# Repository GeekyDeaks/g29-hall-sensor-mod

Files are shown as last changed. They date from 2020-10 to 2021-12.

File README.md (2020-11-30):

# G29 Hall Sensor Mod

Modification to replace the stock potentiometers in the G29/G27 pedals with hall sensors

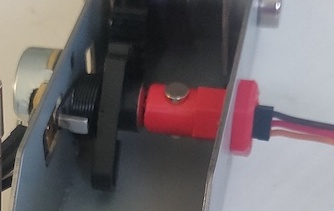
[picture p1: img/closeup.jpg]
closeup


There are two alternative designs in this repo

1. modification using the original pot as part of the magnet holder assembly (as show in the above image)
2. complete replacement of the original pot with a 3D printed design

Both designs require some additional parts to accompany the 3D model

1. 2x 6mm diameter 3mm high magnets
2. [A1324](https://docs.rs-online.com/958c/0900766b813d193a.pdf) hall effect sensor 

# Hall Sensor

Over the 70 degrees rotation the pedal rotates the pot axis, the output of the A1324 is very linear.  The chart below shows the output of the sensor compares to the output of the pot whilst both are connected in the same pedal:

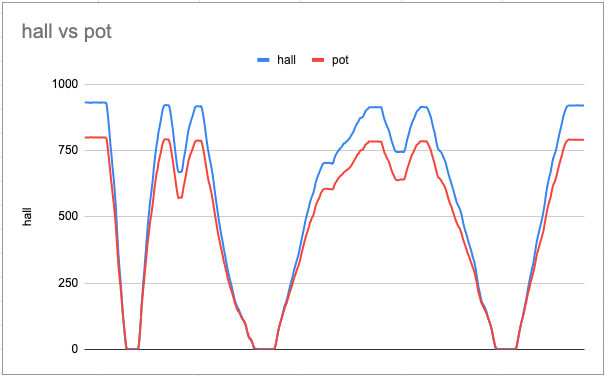
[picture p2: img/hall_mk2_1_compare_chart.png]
compare


The next chart shows an XY scatter of the pot vs the hall sensor readings for each sample taken:

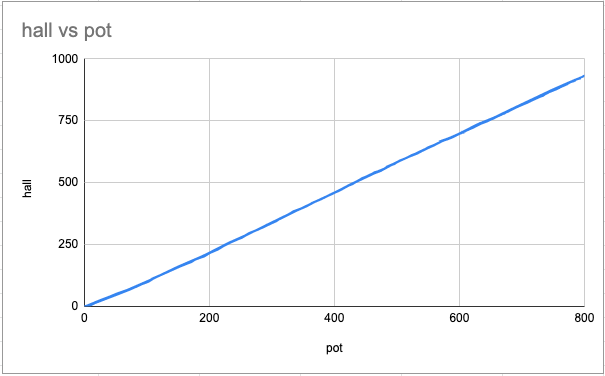
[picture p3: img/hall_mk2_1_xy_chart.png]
xy


The units of each plot are the 10 bit reading of the ADC in a Pro Micro Arduino

The A1324 is rated at 5V, but it was found during testing that it actually works at 3.3V, so it appears to be completely compatible with the G29.  There is however another variant, the [A1319](https://docs.rs-online.com/1a99/0900766b815eefb8.pdf), which is rated at 3.3V

# Mod design

This design engages with the stock potentiometer, using it as the base of the magnet holder.

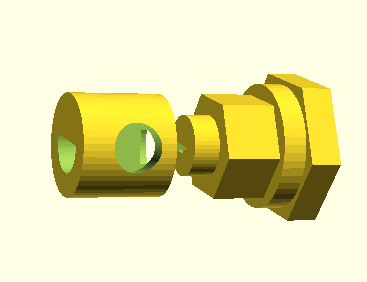
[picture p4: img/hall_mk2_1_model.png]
mod


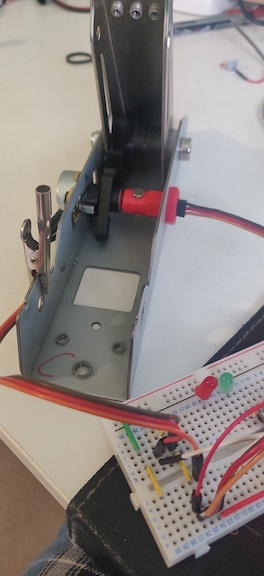
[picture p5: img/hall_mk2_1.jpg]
test


There are two alternatives to this design:

1. where the sensor leads exit the side of the assembly (mod/stl/side-exit-explode.stl)
2. where the sensor leads exit inside the assembly and therefore inside the pedal base (mod/stl/inner-exit-explode.stl)

# Replacement design

This completely replaces the stock potentiometer with a 3D printed replacement.  The tolerances are pretty tight, but can be relaxed a little with some additional silicone grease or suitable alternative.

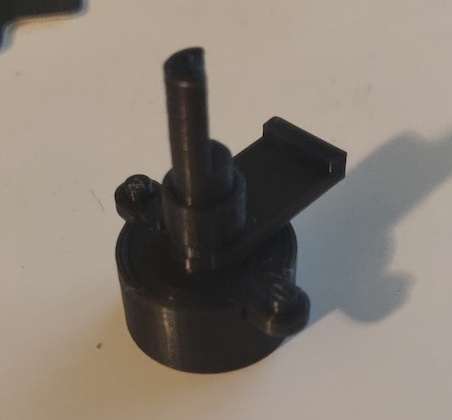
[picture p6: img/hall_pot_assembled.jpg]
assembled

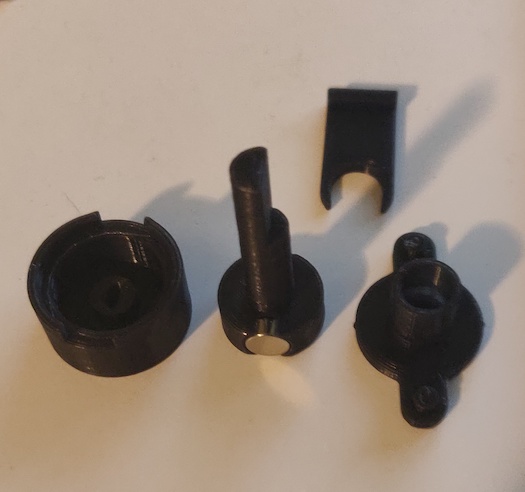
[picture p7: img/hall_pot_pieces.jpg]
explode


## STL

* [explode](pot/stl/explode.stl)
* [clip](pot/stl/clip.stl)
* [front](pot/stl/front.stl)
* [mag-holder](pot/stl/mag-holder.stl)
* [sensor-holder](pot/stl/sensor-holder.stl)

# reference

If you want to see how things took shape or throw in suggestions, you can find some of the musings on racedepartment: https://www.racedepartment.com/threads/g27-g29-hall-sensor-mod.190696/

* A1324 (https://docs.rs-online.com/958c/0900766b813d193a.pdf)
* A1319 (https://docs.rs-online.com/1a99/0900766b815eefb8.pdf)

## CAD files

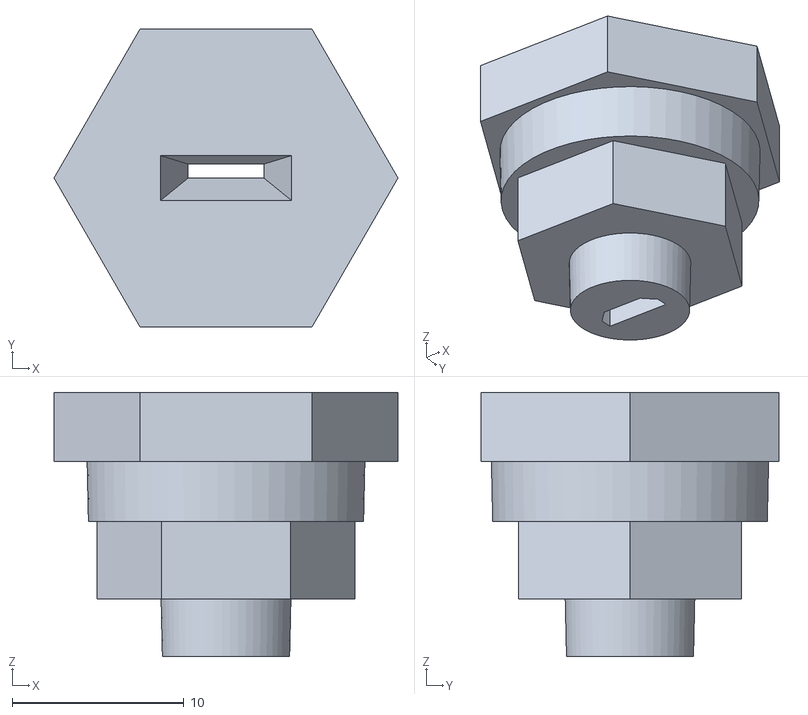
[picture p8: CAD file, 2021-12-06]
mod/stl/side-exit-sensor.stl
20.0 x 17.3 x 15.3

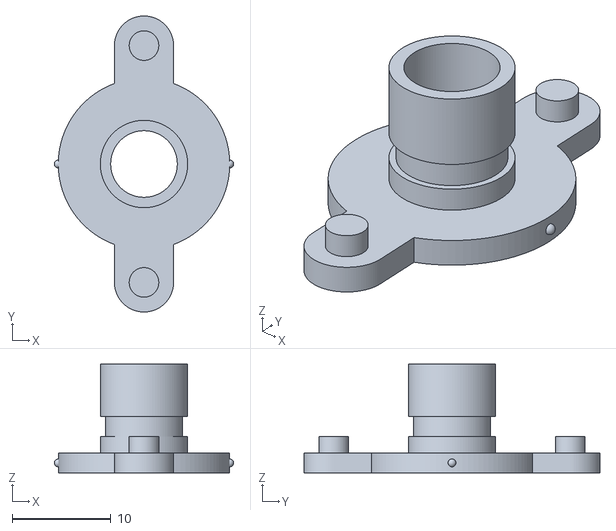
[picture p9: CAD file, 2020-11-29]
pot/stl/front.stl
18.2 x 30.0 x 11.0

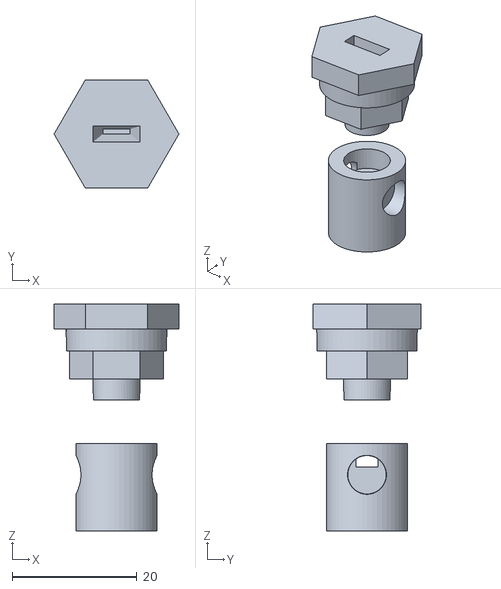
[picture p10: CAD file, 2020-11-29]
mod/stl/side-exit-explode.stl
20.0 x 17.3 x 36.4

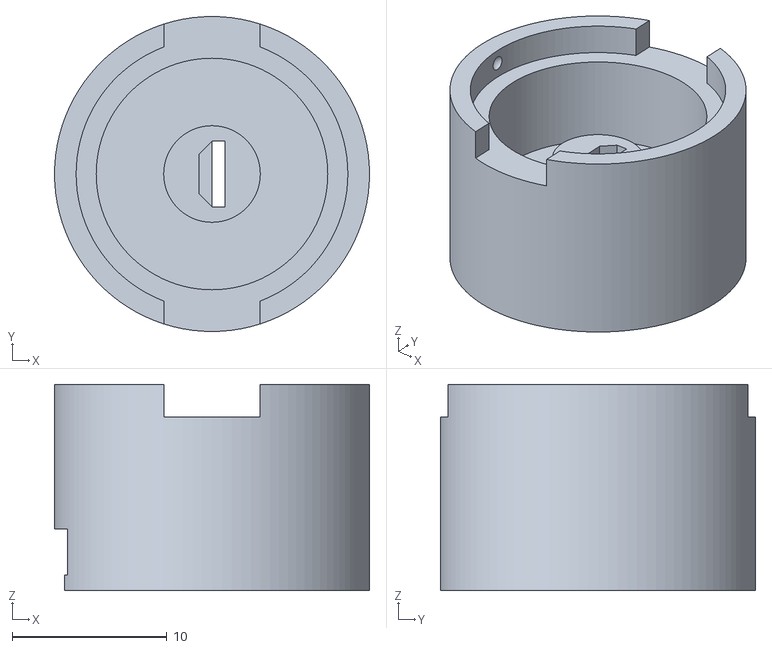
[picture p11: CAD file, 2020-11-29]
pot/stl/sensor-holder.stl
20.4 x 20.4 x 13.3

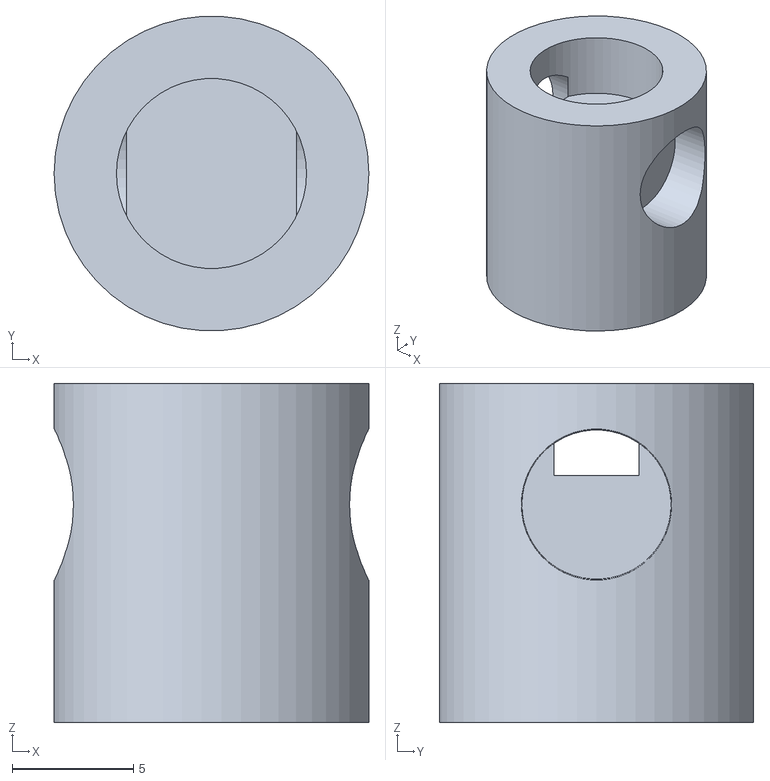
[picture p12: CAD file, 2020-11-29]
mod/stl/side-exit-mag.stl
13.0 x 13.0 x 14.0

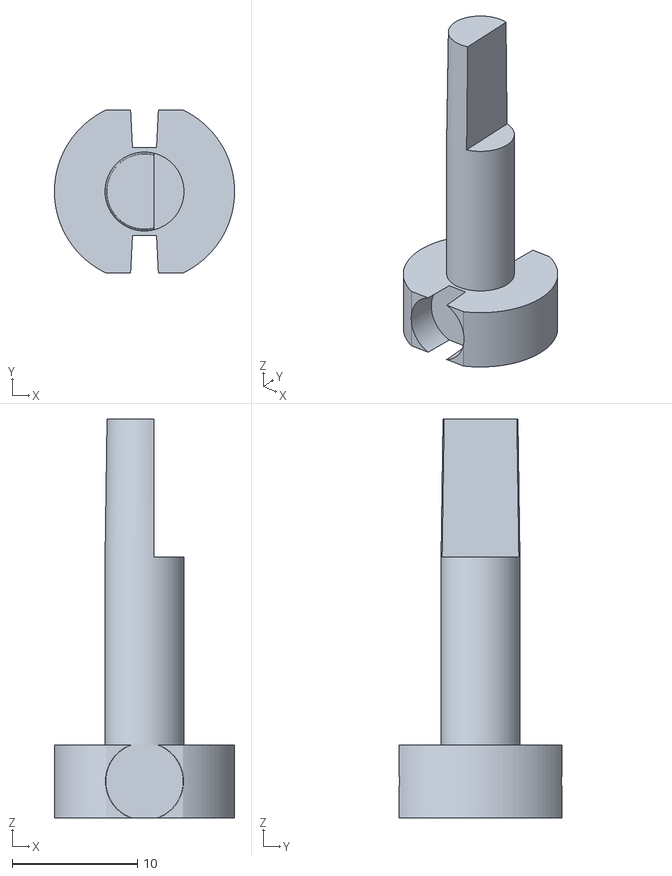
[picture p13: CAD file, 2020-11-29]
pot/stl/mag-holder.stl
14.4 x 13.0 x 31.8

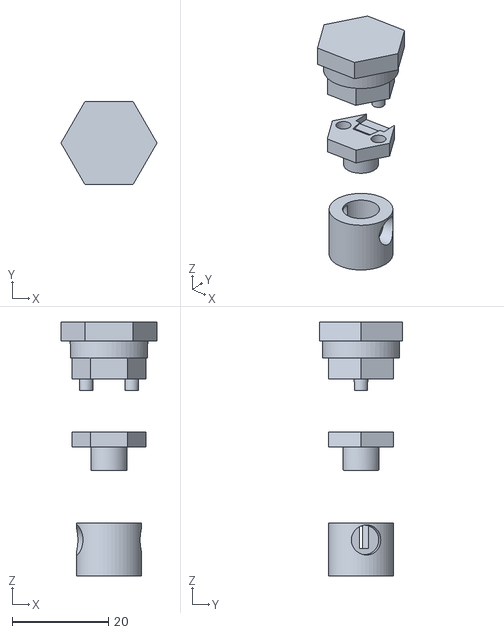
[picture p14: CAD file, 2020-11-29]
mod/stl/inner-exit-explode.stl
20.0 x 17.3 x 52.9

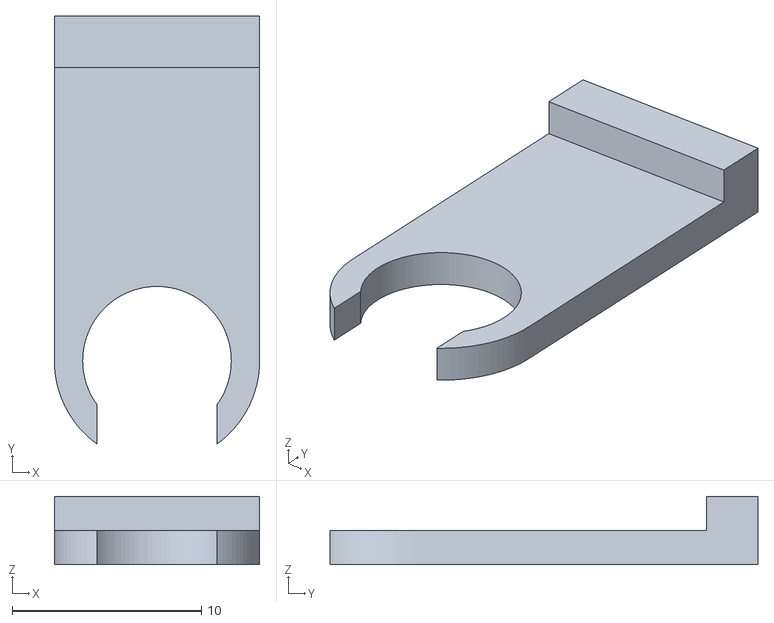
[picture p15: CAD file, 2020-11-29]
pot/stl/clip.stl
10.8 x 22.6 x 3.60

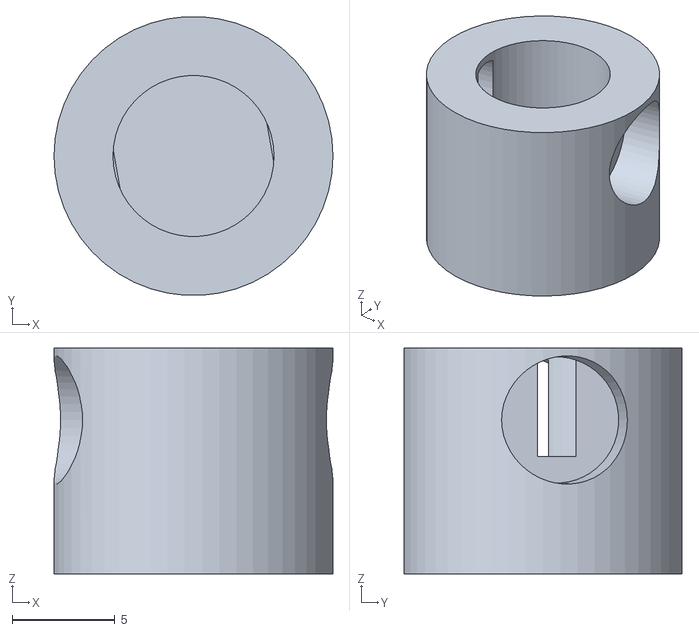
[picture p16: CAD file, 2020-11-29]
mod/stl/inner-exit-mag.stl
13.6 x 13.6 x 11.0

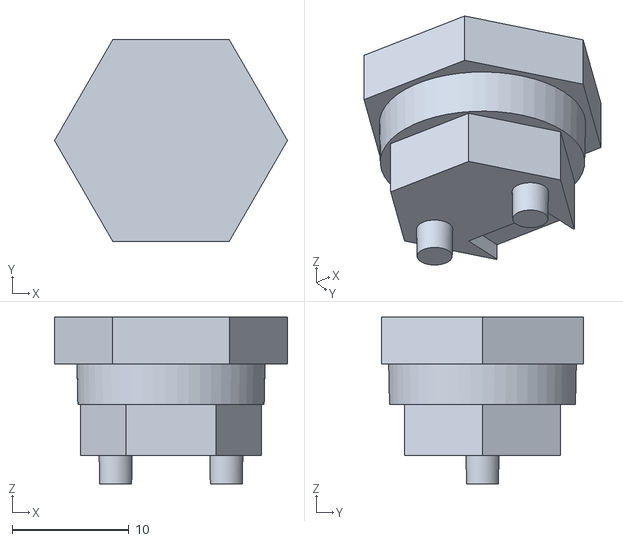
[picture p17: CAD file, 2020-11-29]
mod/stl/inner-exit-lower.stl
20.0 x 17.3 x 14.3

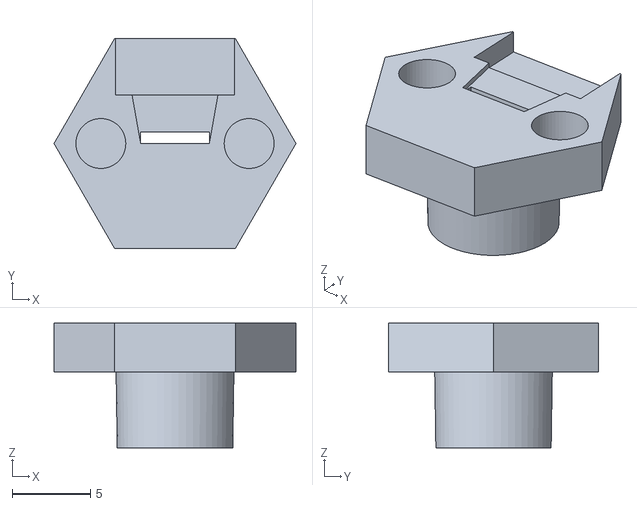
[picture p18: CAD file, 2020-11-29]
mod/stl/inner-exit-upper.stl
15.5 x 13.4 x 8.00

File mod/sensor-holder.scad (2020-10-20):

module sensor_profile() {

    translate([-SENSOR_LEAD_DEPTH, -SENSOR_WIDTH / 2, 0]) 
    polygon([
        [0, 0],
        [0, SENSOR_WIDTH],
        [SENSOR_DEPTH - SENSOR_FRONT_DEPTH, SENSOR_WIDTH],
        [SENSOR_DEPTH, SENSOR_WIDTH - SENSOR_FRONT_DEPTH],
        [SENSOR_DEPTH, 0 + SENSOR_FRONT_DEPTH],
        [SENSOR_DEPTH - SENSOR_FRONT_DEPTH, 0]
    ]);

}

module sensor_holder_body() {

    // solid model of the sensor holder to allow different 
    // lead cutout configurations
    overlap = HOLDER_OVERLAP - 0.15;
    main_width = ASSEMBLY_WIDTH - MAG_HOLDER_LENGTH - BASE_INTERFERENCE_WIDTH;

    // small little guide for the sensor
    difference() {

        // overlap cylinder
        cylinder(d1 = OVERLAP_DIAMETER - 0.3, d2 = OVERLAP_DIAMETER - 0.15, h = overlap);

        translate([0, 0, -.01])
        rotate([0, 0, 270])
        linear_extrude(height = SENSOR_HEIGHT + 0.01, center = false)
        sensor_profile();
    }

    // main hex shaped part
    translate([0, 0, overlap])
    cylinder(d = SENSOR_HOLDER_DIAMETER, h = main_width, $fn = 6);
    // interference cylinder
    translate([0, 0, overlap + main_width])
    cylinder(d1 = BASE_HOLE_DIAMETER - 0.15, d2 = BASE_HOLE_DIAMETER, h = BASE_INTERFERENCE_WIDTH);
    // outer flange
    translate([0, 0, overlap + main_width + BASE_INTERFERENCE_WIDTH])
    cylinder(d = SENSOR_HOLDER_FLANGE_DIAMETER, h = SENSOR_HOLDER_FLANGE_WIDTH, $fn = 6);
}

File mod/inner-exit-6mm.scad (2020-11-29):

$fn = 50;

MAG_DIAMETER = 6.15;
MAG_HEIGHT = 3;
MAG_DISTANCE = 3.8;  // distance of magnet from the sensor centre

ASSEMBLY_WIDTH = 22; // width of the assembly up to the flange

SENSOR_OFFSET = 7.5; // where the midpoint of the sensor will sit from the base of the magnet holder
SENSOR_HOLE_DIAMETER = 5.5;
SENSOR_WIDTH = 4.4;  // physical outer dimensions of the sensor
SENSOR_HEIGHT = 3;
SENSOR_DEPTH = 1.6;
SENSOR_FRONT_DEPTH = 0.85; // distance from front face to pins
SENSOR_LEAD_LENGTH = 9;
SENSOR_LEAD_DEPTH = SENSOR_DEPTH - SENSOR_FRONT_DEPTH;

SENSOR_HOLDER_DIAMETER = 15.5;
SENSOR_HOLDER_FLANGE_DIAMETER = 20; // bit outside the base
SENSOR_HOLDER_FLANGE_WIDTH = 4;

BASE_HOLE_DIAMETER = 16.15;
BASE_INTERFERENCE_WIDTH = 3.5;

OVERLAP_DIAMETER = 7.7;

MAG_HOLDER_DIAMETER = (MAG_HEIGHT + MAG_DISTANCE) * 2;
MAG_HOLDER_LENGTH = 11;
MAG_ROTATION_OFFSET = 100;

POT_SHAFT_HEIGHT = 5;
POT_SHAFT_DIAMETER = 6.4;
POT_SHAFT_RECESS = 2.6;

HOLDER_OVERLAP = MAG_HOLDER_LENGTH - SENSOR_OFFSET + (SENSOR_HEIGHT / 2);

CONN_WIDTH = 7.6;
CONN_PIN_WIDTH = 5.5; // distance between the outer two pins
CONN_DEPTH = 2.6;
CONN_LENGTH = ASSEMBLY_WIDTH - SENSOR_LEAD_LENGTH - MAG_HOLDER_LENGTH + SENSOR_HOLDER_FLANGE_WIDTH + HOLDER_OVERLAP;

include <magnet-holder.scad>;
include <sensor-holder.scad>;


SPLIT_POINT = 8;
DOWEL_DIAMETER = 3;
DOWEL_DEPTH = 2.75;

module upper() {

    difference() {
        intersection() {
            sensor_holder_body();
            translate([0, 0, -SENSOR_HEIGHT])
            cylinder(d = SENSOR_HOLDER_FLANGE_DIAMETER + 0.1, h = SPLIT_POINT + SENSOR_HEIGHT);
        }
        // hole for leads
        // offset hole for leads a little to help centre the sensor
        translate([- (SENSOR_WIDTH / 2), 0, -0.1])
        cube([SENSOR_WIDTH, SENSOR_LEAD_DEPTH, SPLIT_POINT + 0.2]);

        // hole for the connector
        translate([- (CONN_WIDTH / 2), SENSOR_HOLDER_DIAMETER / 5, SPLIT_POINT - CONN_DEPTH / 2 ])
        cube([CONN_WIDTH, SENSOR_HOLDER_DIAMETER / 2, CONN_DEPTH / 2 + 0.1]);

        // recess for leads to be pinched
        translate([0, 0, SPLIT_POINT - 0.3])
        hull() {
            translate([- (SENSOR_WIDTH / 2), 0, 0])
            cube([SENSOR_WIDTH, SENSOR_LEAD_DEPTH, 0.4]);
            
            translate([- (CONN_PIN_WIDTH / 2), SENSOR_HOLDER_DIAMETER / 5, 0])
            cube([CONN_PIN_WIDTH, SENSOR_HOLDER_DIAMETER / 2, 0.4]);
        }

        // dowel holes
        translate([SENSOR_HOLDER_DIAMETER / 2 - DOWEL_DIAMETER, 0, SPLIT_POINT - DOWEL_DEPTH - 0.1])
        cylinder(d = DOWEL_DIAMETER + 0.2, h = DOWEL_DEPTH + 0.2);

        translate([-SENSOR_HOLDER_DIAMETER / 2 + DOWEL_DIAMETER, 0, SPLIT_POINT - DOWEL_DEPTH - 0.1])
        cylinder(d = DOWEL_DIAMETER + 0.2, h = DOWEL_DEPTH + 0.2);

        
    }

    // dowels
    *translate([SENSOR_HOLDER_DIAMETER / 2 - DOWEL_DIAMETER, 0, SPLIT_POINT])
    cylinder(d = DOWEL_DIAMETER - 0.3, h = DOWEL_DEPTH - 0.3);


    *translate([-SENSOR_HOLDER_DIAMETER / 2 + DOWEL_DIAMETER, 0, SPLIT_POINT])
    cylinder(d = DOWEL_DIAMETER - 0.3, h = DOWEL_DEPTH - 0.3);


}

module lower() {
    difference() {
        intersection() {
            sensor_holder_body();
            translate([0, 0, SPLIT_POINT])
            cylinder(d = SENSOR_HOLDER_FLANGE_DIAMETER + 0.1, h = ASSEMBLY_WIDTH);

        }
        // dowel holes
        *translate([SENSOR_HOLDER_DIAMETER / 2 - DOWEL_DIAMETER, 0, SPLIT_POINT - 0.1])
        cylinder(d = DOWEL_DIAMETER + 0.2, h = DOWEL_DEPTH + 0.2);

        *translate([-SENSOR_HOLDER_DIAMETER / 2 + DOWEL_DIAMETER, 0, SPLIT_POINT - 0.1])
        cylinder(d = DOWEL_DIAMETER + 0.2, h = DOWEL_DEPTH + 0.2);

        // connection lower hole
        translate([0, 0, SPLIT_POINT - 0.1])
        translate([- (CONN_WIDTH / 2), SENSOR_HOLDER_DIAMETER / 5, 0])
        cube([CONN_WIDTH, SENSOR_HOLDER_DIAMETER / 2, CONN_DEPTH / 2 + 0.1]);

    }

    // dowels
    translate([SENSOR_HOLDER_DIAMETER / 2 - DOWEL_DIAMETER, 0, SPLIT_POINT - DOWEL_DEPTH + 0.3])
    cylinder(d1 = DOWEL_DIAMETER - 0.25, d2 = DOWEL_DIAMETER - 0.15, h = DOWEL_DEPTH);

    translate([-SENSOR_HOLDER_DIAMETER / 2 + DOWEL_DIAMETER, 0, SPLIT_POINT - DOWEL_DEPTH + 0.3])
    cylinder(d1 = DOWEL_DIAMETER - 0.25, d2 = DOWEL_DIAMETER - 0.15, h = DOWEL_DEPTH);

}

if(PART == "explode") {
    mag_holder();
    translate([0, 0, MAG_HOLDER_LENGTH * 2])
    upper();
    translate([0, 0, MAG_HOLDER_LENGTH * 3])
    lower();
}

if(PART == "mag") mag_holder();
if(PART == "lower") lower();
if(PART == "upper") upper();

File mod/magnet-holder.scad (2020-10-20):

module copy_mirror(vec=[0,1,0]) 
{ 
    children(); 
    mirror(vec) children(); 
}

module pot_shaft_hole() {

    radius = POT_SHAFT_DIAMETER / 2;
    width = POT_SHAFT_DIAMETER - POT_SHAFT_RECESS;

    translate([0,0,POT_SHAFT_HEIGHT])
    rotate([180,0,0])
    linear_extrude(height = POT_SHAFT_HEIGHT, scale = 1.1) 
    intersection() {
        circle(radius);
        translate([-radius, -radius]) square([POT_SHAFT_DIAMETER, width]);
    }

}

module mag_holder() {

    difference() {
        cylinder(d = MAG_HOLDER_DIAMETER, h = MAG_HOLDER_LENGTH);
        translate([0, 0, -0.01])
        pot_shaft_hole();

        // holes for magnets
        rotate([0, 0, MAG_ROTATION_OFFSET])
        copy_mirror()
        translate([0, -MAG_DISTANCE , SENSOR_OFFSET]) 
        rotate([90, 0, 0]) 
        cylinder(d1 = MAG_DIAMETER, d2 = MAG_DIAMETER + 0.2, h = MAG_HEIGHT * 2 );

        // hole for overlap between the holders
        translate([0, 0, MAG_HOLDER_LENGTH + 0.01])
        rotate([0, 180, 0])
        cylinder(d = OVERLAP_DIAMETER + 0.15, h = HOLDER_OVERLAP + 0.3);

    }
    
}

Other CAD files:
mod/side-exit-6mm.scad
pot/pot.scad

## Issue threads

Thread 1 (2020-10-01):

Order Form

Skidude88, 2020-10-01:
How do I place my order? 🤣

GeekyDeaks, 2020-10-02:
Ask nicely and bring beer...

Skidude88, 2020-10-02:
Pro-forma?  😁

Will it work on console? Other G2x hall mods say pc only, (guessing due to no calibration on ps4)

GeekyDeaks, 2020-10-02:
working on it! quietly confident, although my grasp of magnetic field mechanics is a little shoddy, so resorting to a liberal dash of trial and error :D

neilser, 2020-10-04:
I am pretty sure that the G27 will behave in an identical fashion to how it behaves with the pots, because it internally self calibrates on every power-up (in fact, I think on every reconnection of the pedal connector, but I can't remember).
I don't have a G29, and I seem to recall that their "auto calibration" behaviour is just a little different, so maybe more scope for issues...?

isopix, 2020-10-25:
Hi,

It's awesome. Previously CellMod and now hall sensors for G29 ^^   I will be interested in both mods x2. Waiting for list of components to buy and some photos/renders.

The only thing is lacking is documentation. No photos, no info what sensors to buy, but I guess it's in early stage. Github doesn't show preview for .SCAD files, so I can only guess from separate magnet mounts, it doesn't use integrated rotary hall sensors (that can be mechanically used in place of pots, have you considered them? People put them in joysticks[to replace weaed-off]. Probably your solution is better, only wondered if you know about them ;-)

I wonder if it will require Arduino, or something like that, so wouldn't it be smart to share microcontroller (and firmware) with @Skidude88 digital cellmod. Does @Skidude88 latest design got any disadvantages (in it's latest form) over you analog CellMod or is it simply way to go now?

P.S. Sorry for not replying so long, but was cheated by one seller (wanted to buy 2nd G29 to build two simulator for kids), but was very dissapointed when judge rejected the case in the end, and lost interest with tinkering with that stuff. I'm still planning to buy second wheel, but prices of used wheels are still 3x higher than two years ago (when sim fans started massively buying DD wheels, selling old stuff very cheaply, because marked saturation.). Logitech pumps up prices too with every revision, so Logitech wheels costs nearly as much as Thrustmaster ones(which doesn't work on linux unfortunately)
 I'm still hunting for occasion and even did some research some time ago and from information I gathered Logitech G29(and newer) doesn't work without PCB inside wheel(not base), so it's very hard to make replaceble wheels, because original(and 2rd party) PCBs are very picey. G27(and G25) works without this PCB(but they are so cheap I bought box of them), but G25 and G27 are usually as pricey as G29/G920 or photos are so bad that's hard to guess condition and it's generally risky to buy so old, used. bechanical stuff trough internet...

best regards and thanks for sharing your hard work with community for free!

GeekyDeaks, 2020-10-25:
Hi @isopix - sorry about the lack of documentation.  I'm still playing around at the moment, but if you want to see what they look like you can check it out in a thread here: https://www.racedepartment.com/threads/g27-g29-hall-sensor-mod.190696/post-3267392

I think it will be compatible with the G29 wheelbase, but I haven't got around to testing yet

isopix, 2020-10-26:
Thanks for the reply. I think you can put link to this thread on
github page, to avoid flood of questions about that.
As I understand from racedepartment thread it's solution that already
gives similar results to stock pot(being less noisy), so already can
be used ad drop in replacement. Is it finished product, or WIP still,
and it's better to wait with ordering parts?

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

GeekyDeaks, 2020-10-26:
Hi @isopix - it's definitely still WIP, but I'm hoping to wrap it up in a week or two.

The plan has always been to make it a drop-in replacement if at all possible and it's looking very promising, but I want to test it with the G29 wheelbase this week to confirm.

It needs a bit of calibration during installation to make sure the range is ok, which is basically twisting the hall sensor holder until the rest voltage is the same as the pot.

GeekyDeaks, 2020-11-29:
hey @isopix - updated the repo with some images and also an alternative design which completely replaces the pot instead

isopix, 2020-11-30:
Thanks for the reply.

You got one "sesno" typo.

I understand that you've tested A1314, but you are recommending A1324,
but A1319 would be betteer suited for G29?

And for brake pedal, do you recommends cell-mod instead of this, also
for cheap/simple stands? (I was reading that for cell mods, you needs
solid rig with mounted seat)

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

GeekyDeaks, 2020-11-30:
A1314 is another typo 😄  should be A1324

Surprisingly, the A1324 works fine at 3.3v - so I never got around to buying the A1319, but since it is officially rated for 3.3v, it might be the better choice

Still recommend the load cell mod for the brake.  This doesn't really help for anything other than dirty/noisy potentiometers.  You will need a sturdy setup, but you can get away with linking the pedals to your seat rather than a full rig

LuckyTite, 2022-06-11:
Good Day.

i would like to ask, i am new to the SIM racing and modding scene, and have a little electronics background.

1. does this replace the pots?
   a. can it be wired directly into a g29 wheelbase?
   b. or do i need an ardu board
2. how does the wiring go?

im planning to buy a second hand g29 and i want to test this out, i have access to 3d printing.

GeekyDeaks, 2022-06-11:
Hi!

> 1. does this replace the pots?

Electrically yes, physically no, it is designed to engage with the potentiometer shaft.  I did make another model (the black PLA one) that is a complete replacement pot, but I never used it for an extended period of time so I'm not sure if it would be reliable enough (although I guess you could just print a replacement when required)

>    a. can it be wired directly into a g29 wheelbase?
>    b. or do i need an ardu board

It is voltage compatible with the G29 wheelbase.  The purpose of this was to make sure it could still be used on a PS4.  The strength of the magnets and their distance from the sensor are important though, so you might need to tweak the spacing in the model to make sure it doesn't saturate the sensor.  I'd probably advise measuring the voltage levels prior to starting to get a reference

> 2. how does the wiring go?

The A1324 has 3 pins. VCC, GND and VOUT, so you simply measure which ones are VCC and GND on your pot and then connect them appropriately with the remaining signal wire from the central pin on the pot going to VOUT

> im planning to buy a second hand g29 and i want to test this out, i have access to 3d printing.

Good luck!  I have replaced my G29 now, but I got a good two years of fun out of it and it's a really great wheel and pedal set for the price.

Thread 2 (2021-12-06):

side_exit_sensor.stl is a duplicate of side_exit_mag.stl

Tabby, 2021-12-06:
I just noticed that side_exit_sensor.stl is a duplicate of side_exit_mag.stl and not actually the sensor housing at all >_<

This mod looks great though and I look forward to trying it :)

GeekyDeaks, 2021-12-06:
Doh! I thought I had fixed that ages ago!  Just pushed the changes in bc9f145

Tabby, 2021-12-06:
That was fast! Thanks very much 😁

Closed 2021-12-06.

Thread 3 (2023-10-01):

Moves up when pedal is depressed

cciRRus, 2023-10-01:
Hi there!

I am very grateful for this project, thank you so much! I've done the "Replacement Design" with the super cheap **49E** hall effect sensor. It works fine on G29, while I play Gran Turismo 7 on PS4.

There is a slight issue. When my throttle pedal is fully depressed, the entire device lifts up. I don't have a photo of the actual issue because I forgot to take a photo before assembling the pedal. But the issue looks something like this:

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

I made sure the whole replacement is as tightly secured as possible, especially the Clip. Yet this happens.

While the thing works for now, I'm not sure if it will last. Repetitive up/down movements over time may wear out the 3D printed device. Is this behavior expected?

neilser, 2023-10-01:
Sounds like you may have a misalignment - the black gearwheel in the picture may not be engaging in the right place with the gearwheel connected to the pedal.
Or do you mean that it moves when the pedal is fully _released_? That would be pretty normal, if the leg on the gearwheel pictured is resting on the metal when the pedal is released. (It has never been 100% clear to me if that's the correct location when released or if it should be one tooth further along, but my best guess is that "resting on the metal" is the correct location.)

GeekyDeaks, 2023-10-29:
Hi! Sorry, I completely missed the notification for this.  I agree with @neilser - if it's happening when you full depress the pedal, then that doesn't sound right and something is amiss.  If it's when you release the pedal, this is something I noticed happened on the original pedals before I started this mod and as @neilser mentioned, appears to be when the leg on the gearwheel contacts the base.  I simply rotated the gear around one tooth when using the mod to prevent it from happening on my prints.

cciRRus, 2023-10-31:
This is how the **original setup** looks like:
https://github.com/GeekyDeaks/g29-hall-sensor-mod/assets/84564999/6ae5fff8-0e72-4be0-a5fd-3e9819e8b55b

This is because the **original potentiometer** has a tight fit:
https://github.com/GeekyDeaks/g29-hall-sensor-mod/assets/84564999/0b52dc9c-db9a-46f6-8c30-0584abe72edd

This is how my 3D printed **Replacement Design** looks like:
https://github.com/GeekyDeaks/g29-hall-sensor-mod/assets/84564999/cea5fd19-4f5d-4c0a-9e97-e935a02f8652

This is because there is quite a bit of play between the **Replacement Design** shaft and the holder:
https://github.com/GeekyDeaks/g29-hall-sensor-mod/assets/84564999/05840033-f53b-4296-96dc-76f8b9a30c07

cciRRus, 2023-10-31:
FYI, I tried aligning the gear meshing at +1 or -1 tooth, but it does not help.

GeekyDeaks, 2023-10-31:
oh, this is with the 3D pot!  Sorry, I totally misunderstood and thought it was the mod that attaches to the original pot.  I'll need dig out an old model to check, but I don't remember anywhere near that amount of play.  I'll be honest, I only really did that for a bit of fun and for others to experiment with and I never used it myself.  I suspect I made the model with the tolerances for my Ender 3, so if your printer is more accurate you might need to just make the inner diameter of the piece the shaft goes through a tiny bit smaller or the shaft diameter a tiny bit larger.  I'll check which variables in the SCAD file adjusts this later tonight.

One other thing to note - I seem to remember that things were much better with that model when it was packed with grease, all the way to where the shaft exits the model.

neilser, 2023-10-31:
I had (like @GeekyDeaks) failed to spot the mention of "Replacement Design" in the original post above.
The videos make it very clear that the lifting up happens when the pedal is fully _released_ - which is normal. However the amount of play is higher than I saw with the replacement design and may indicate that your printer doesn't behave quite the same way as the one @GeekyDeaks used when printing the one I tested.
Nonetheless, I would have expected that you should be able to eliminate the up/down movement by rotating the arm 1 notch clockwise (as seen in the third video) because then the arm will never touch the metal base and reverse the loading.
Also, while I'd like to see the amount of play in the motion reduced (i.e. tighter fit) I doubt that wear would be a big deal even as-is, because the movement isn't caused by the pedal forces per se, but rather by the not-very-strong spring on the pot which keeps it engaged with the teeth in the pedal (until the arm hits the metal base).
Sorry for the essay - hope some of that makes sense ;)

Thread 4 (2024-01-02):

`mag_holder` and `shaft` are not one part

wucke13, 2024-01-02:
Because they are not combined within a union, upon "split parts into objects" in prusa slicer the exploded view would generate me a separate shaft and a separate magnetholder. But I guess magentholder and shaft are meant to be one part?

Code: https://github.com/GeekyDeaks/g29-hall-sensor-mod/blob/master/pot/pot.scad#L76-L101

The same holds true for the small cylinder around the actual sensor and the base

GeekyDeaks, 2024-01-05:
Ah, by default scad does a `union`, so it should already be that way, but reviewing the model again I see something else I overlooked.  I suspect the problem may be because there is 0 overlap between the magnet holder and the shaft.  You could try adjusting the offset of the shaft by a tiny amount e.g.

`translate([0, 0, height - 0.001 ])`

wucke13, 2024-07-20:
I have a big PR with many changes, including a fix for this in #5 . Some of these changes are about taste, so I'm not 100% sure whether you should merge it - if not others may choose.

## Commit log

2020-09-24 tweaks to get everything to fit
    [mag-holder.stl, magnet-holder-6mm-dual.scad, sensor-holder.stl]
2020-09-24 correct magnet hole calculation
    [mag-holder.stl, magnet-holder-6mm-dual.scad, sensor-holder.stl]
2020-09-25 add holes for sensor test
    [mag-holder.stl, magnet-holder-6mm-dual.scad, sensor-holder.stl]
2020-09-27 add inner exit model
    [magnet-holder-6mm-dual.scad]
2020-10-18 split model to allow different connector point
    [inner-exit-6mm.scad, inner-exit-split-6mm.scad, magnet-holder-6mm-dual.scad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]
2020-10-20 tweaks to dowels and sensor profile
    [inner-exit-split-6mm.scad, magnet-holder.scad, sensor-holder.scad]
2020-10-22 add print.scad
    [print.scad]
2020-11-23 add pot version
    [pot.scad]
2020-11-23 increase tolerance on front
    [pot.scad]
2020-11-24 add clip
    [pot.scad]
2020-11-24 adjust clip
    [pot.scad]
2020-11-25 add dupont connector recess
    [pot.scad]
2020-11-29 tidy up
    [clip.stl, front.stl, inner-exit-6mm.scad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]
2020-11-29 add explode for side exit
    [side-exit-explode.stl, side-exit-mag.stl]
2021-12-06 correctly export side-exit-sensor
    [side-exit-6mm.scad, side-exit-sensor.stl]
2024-01-02 chpore: remove magic numbers
    Previously there was a lot of 0.001 and 0.002 sprinkled across the
    source code. This commit introduces a new constant EPS which is
    reasonably small to not change anything in the mechanical side,
    but to please on the various instances of floating point weirdness.
    Subsequently, all instances of the magic numbers are replaced by EPS or
    multiples of EPS.
    [pot.scad]
2024-01-02 chore: remove excessive whitespace
    Removes whitespace, such as trailing spaces and flocks of newlines.
    [pot.scad]
2024-01-02 feat: simplify shaft
    These changes simplify the construction of the shaft, removing the
    chance of getting a multiple bodies due to floating point weirdness.
    [pot.scad]
2024-01-02 The basic change makes the shaft interfere with the
    [pot.scad]
2024-01-02 fix: avoid split bodies on mag_holder
    This change makes the shaft interfere completely with the actual
    cylinder holding the magnets. By doing so, the chance of shaft and
    magnet holder cylinder being considered split bodies is removed.
    [pot.scad]
2024-07-07 final tightness overhaul
    [pot.scad]
